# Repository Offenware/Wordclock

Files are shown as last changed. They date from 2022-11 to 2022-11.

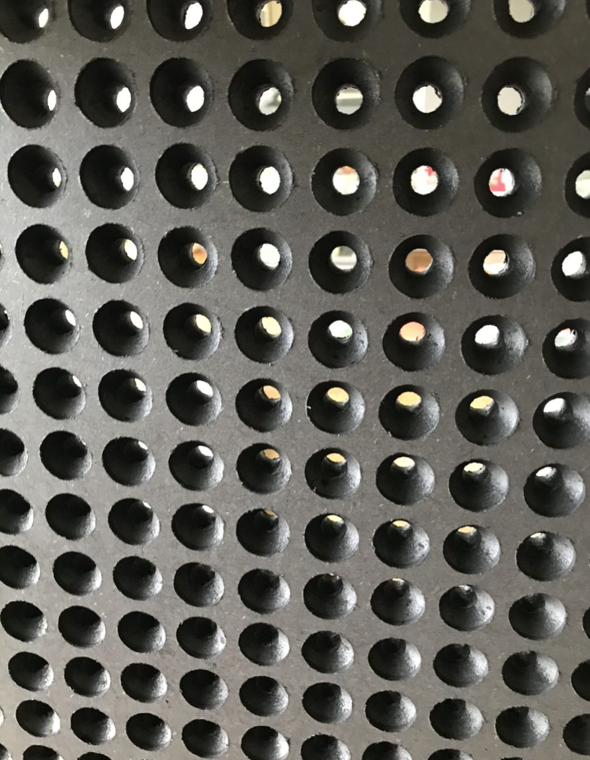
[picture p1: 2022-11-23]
Photos/Knipsel6.PNG

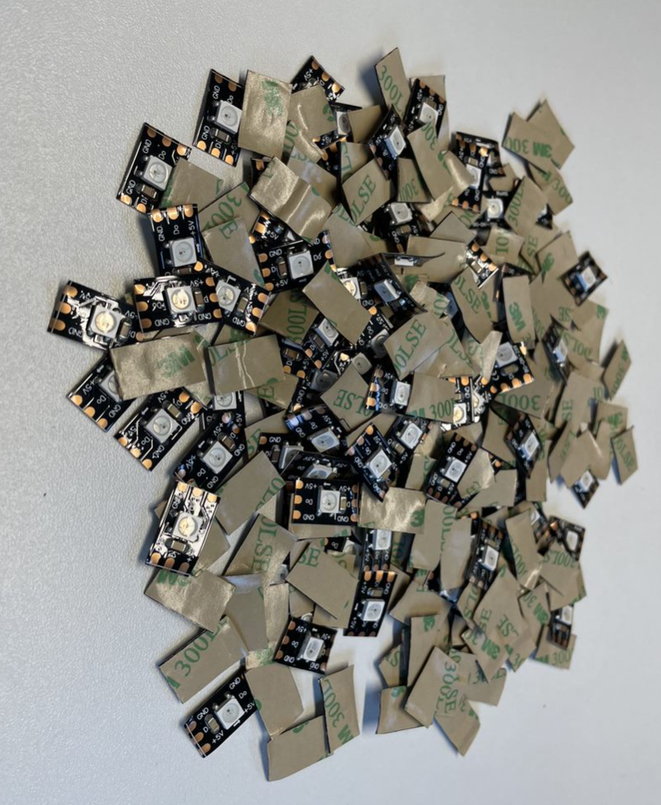
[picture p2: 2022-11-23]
Photos/Knipsel8.PNG

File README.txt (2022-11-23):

# Wordclock
THIS IS NOT A MANUAL, YOU HAVE TO FIGURE OUT HOW TO BUILD IT YOURSELF

Added pictures for some clarity

These are the sources for my Wordclock project. 
Lots of things are in Dutch since I never planned to go public with it, so you have to do some figuring out.
On the other hand, I figured out a lot that you now can use.
Also, be aware that still a lot of improvements can be made on both software and components.

I used a lot of stuff that's on the internet to start out with, so most of it is not originally mine.

The faceplate
I created the face plate in Inkscape and adjusted the DroidSansMono.ttf to meet my needs in FontForge
https://inkscape.org/release/inkscape-1.2.1/windows/64-bit/msi/?redirected=1
https://fontforge.org/en-U

For hardware I used:
5 meters WS2812b digital RGB ledstrip Premium Model: DS12BLS60-05M0520
40 Watt - 5V / 8A adapter for USB led strips Model: AD05-08PT
Between the Faceplate and the Backplate I used a sample of ORACAL® 8500 Translucent Color: 8500-010 White
The Backplate is MDF black 500x500 mm, 22 mm thick
Arduino Mega2560Pro
nodemcu esp32-s 38 pins (many types available)
DS3231 clock
BME260 sensor for fun
Diode and resisters where needed

Designed PCB's to hold the LEDs and the Arduino and Clock etc, designed them in Fritzing, ordered it at https://aisler.net/

Tip: Don't solder the Leds on the backstrips any hotter than 290 degrees Celcius or they'll get damaged and you'll spend a lot of time replacing bad ones.
Talking from experience here :-(

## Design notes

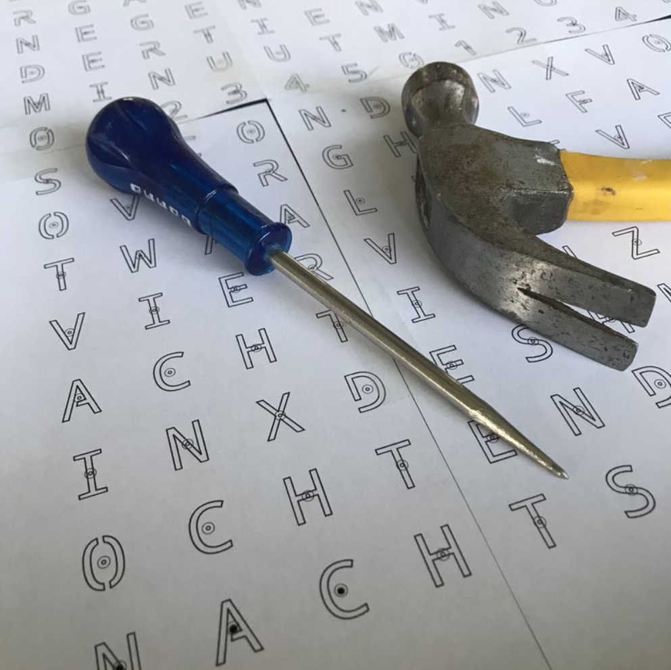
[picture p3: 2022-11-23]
Photos/Knipsel2.PNG

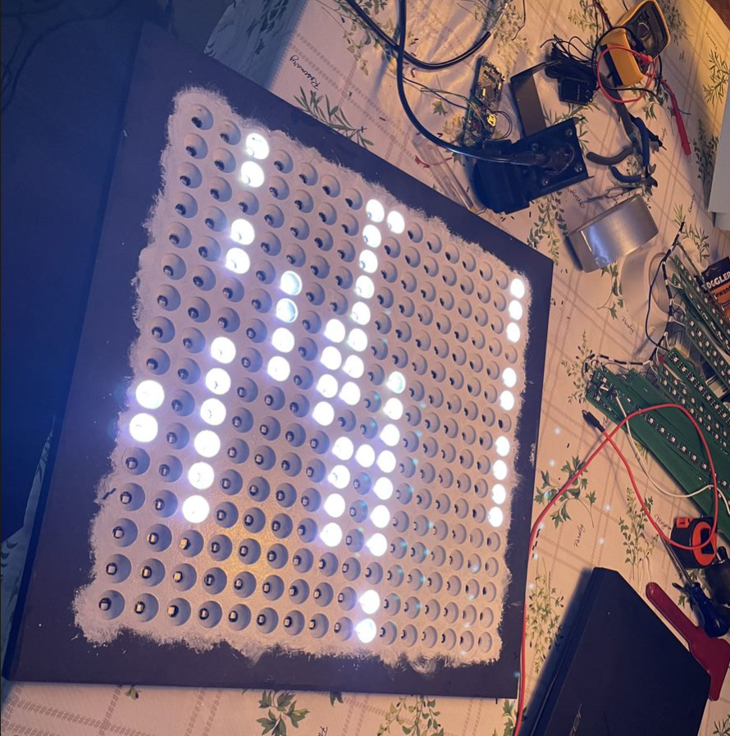
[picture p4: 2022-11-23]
Photos/Knipsel16.PNG

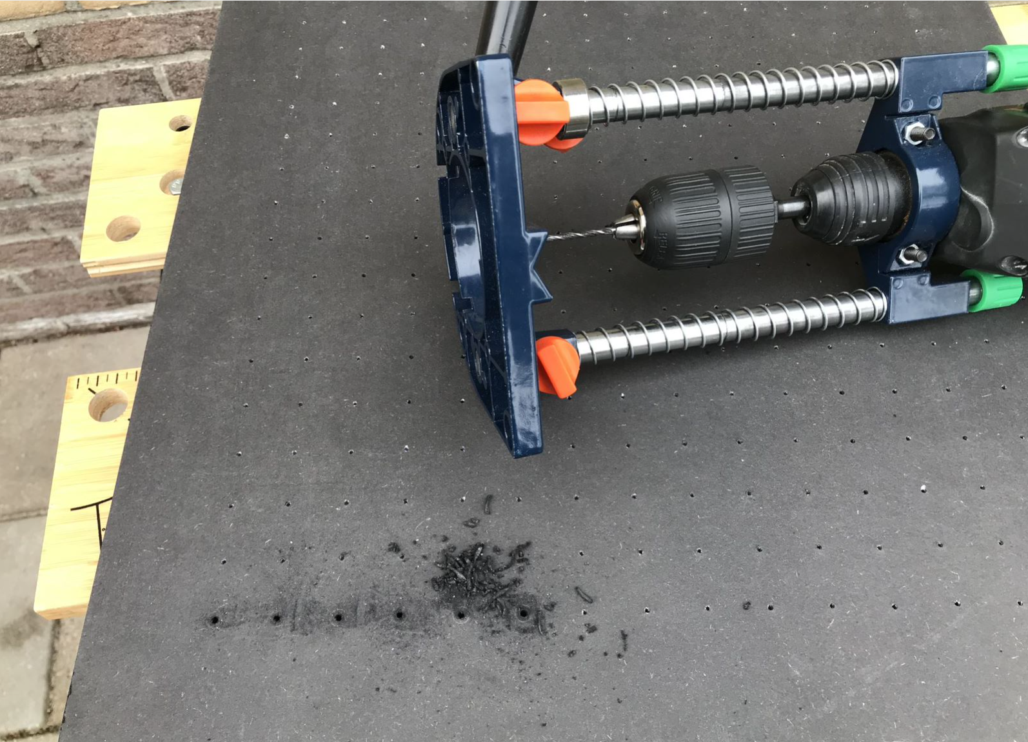
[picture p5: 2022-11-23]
Photos/Knipsel3.PNG

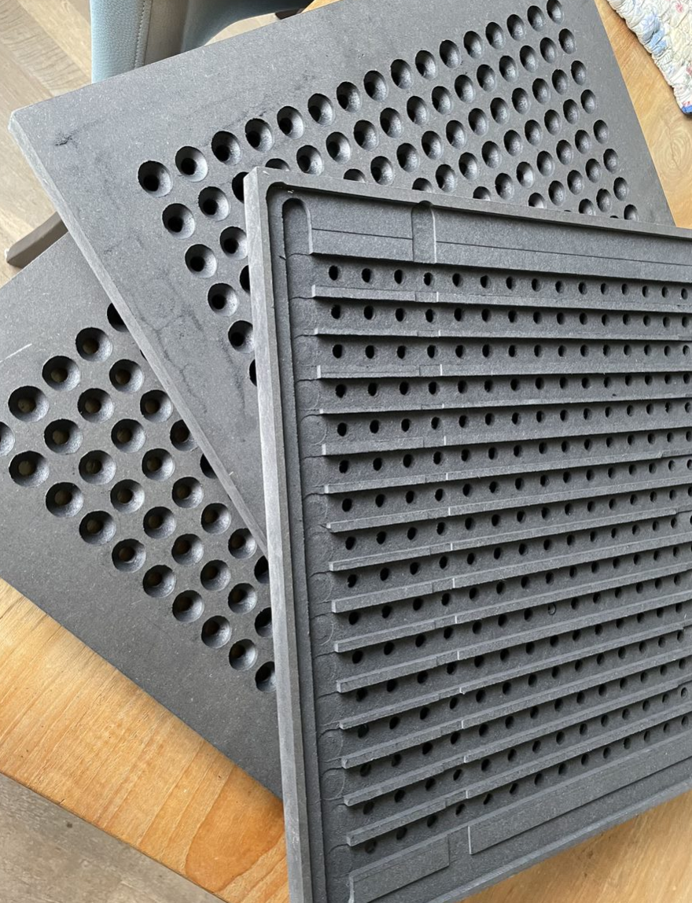
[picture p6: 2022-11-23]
Photos/Knipsel11.PNG

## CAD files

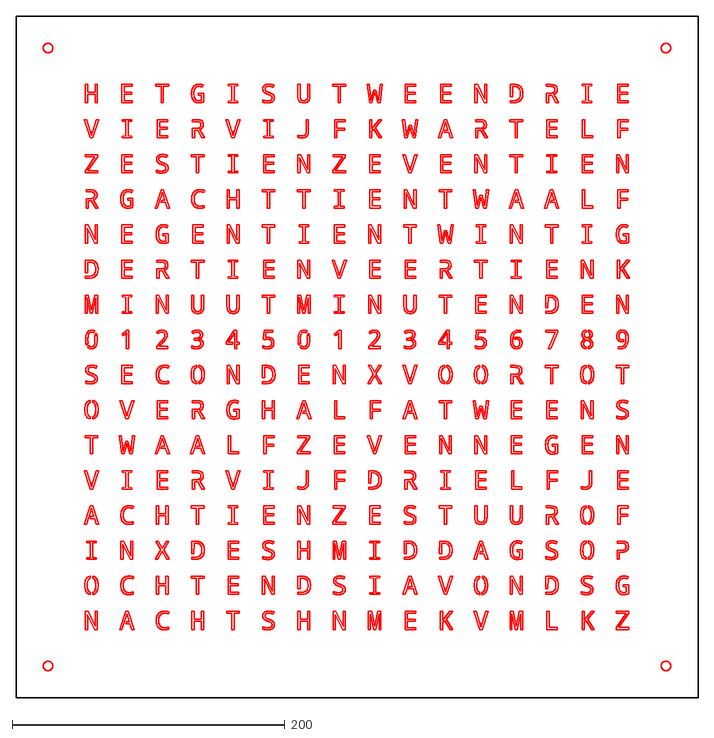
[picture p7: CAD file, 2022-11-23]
Faceplate/wettersnijer.dxf
500.0 x 500.0

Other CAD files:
Faceplate/Inkscape/voorkant.dxf

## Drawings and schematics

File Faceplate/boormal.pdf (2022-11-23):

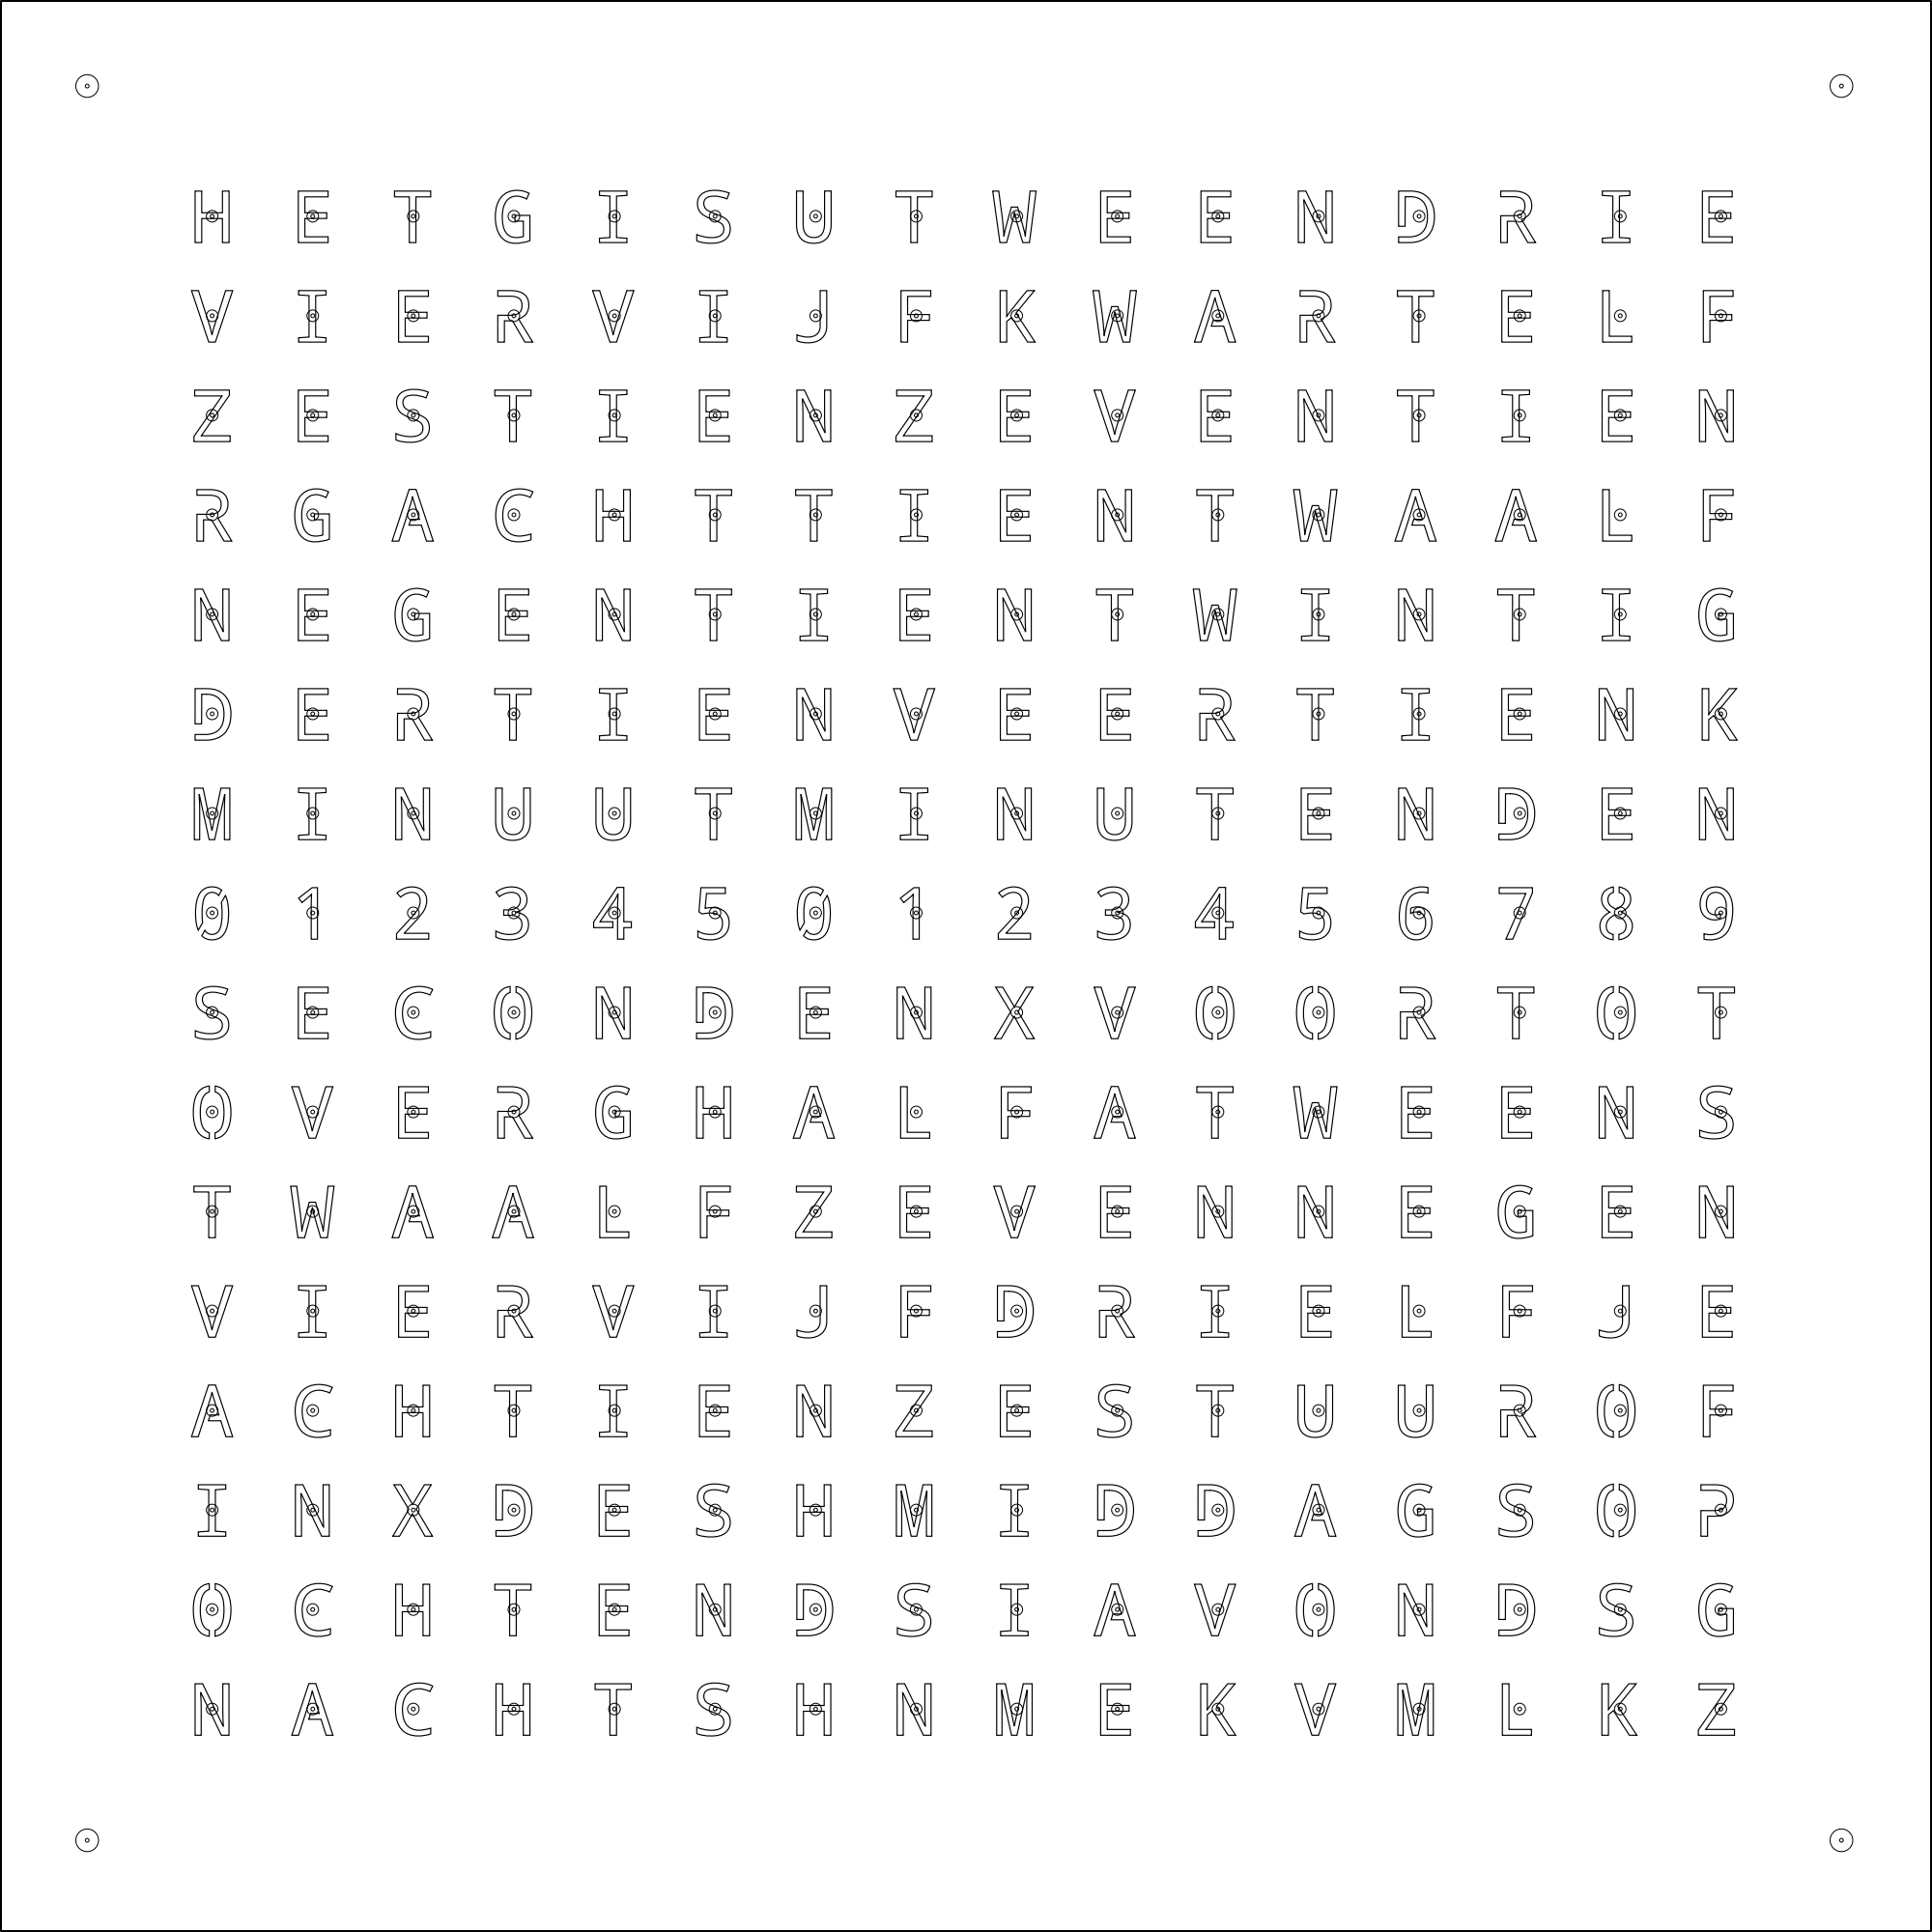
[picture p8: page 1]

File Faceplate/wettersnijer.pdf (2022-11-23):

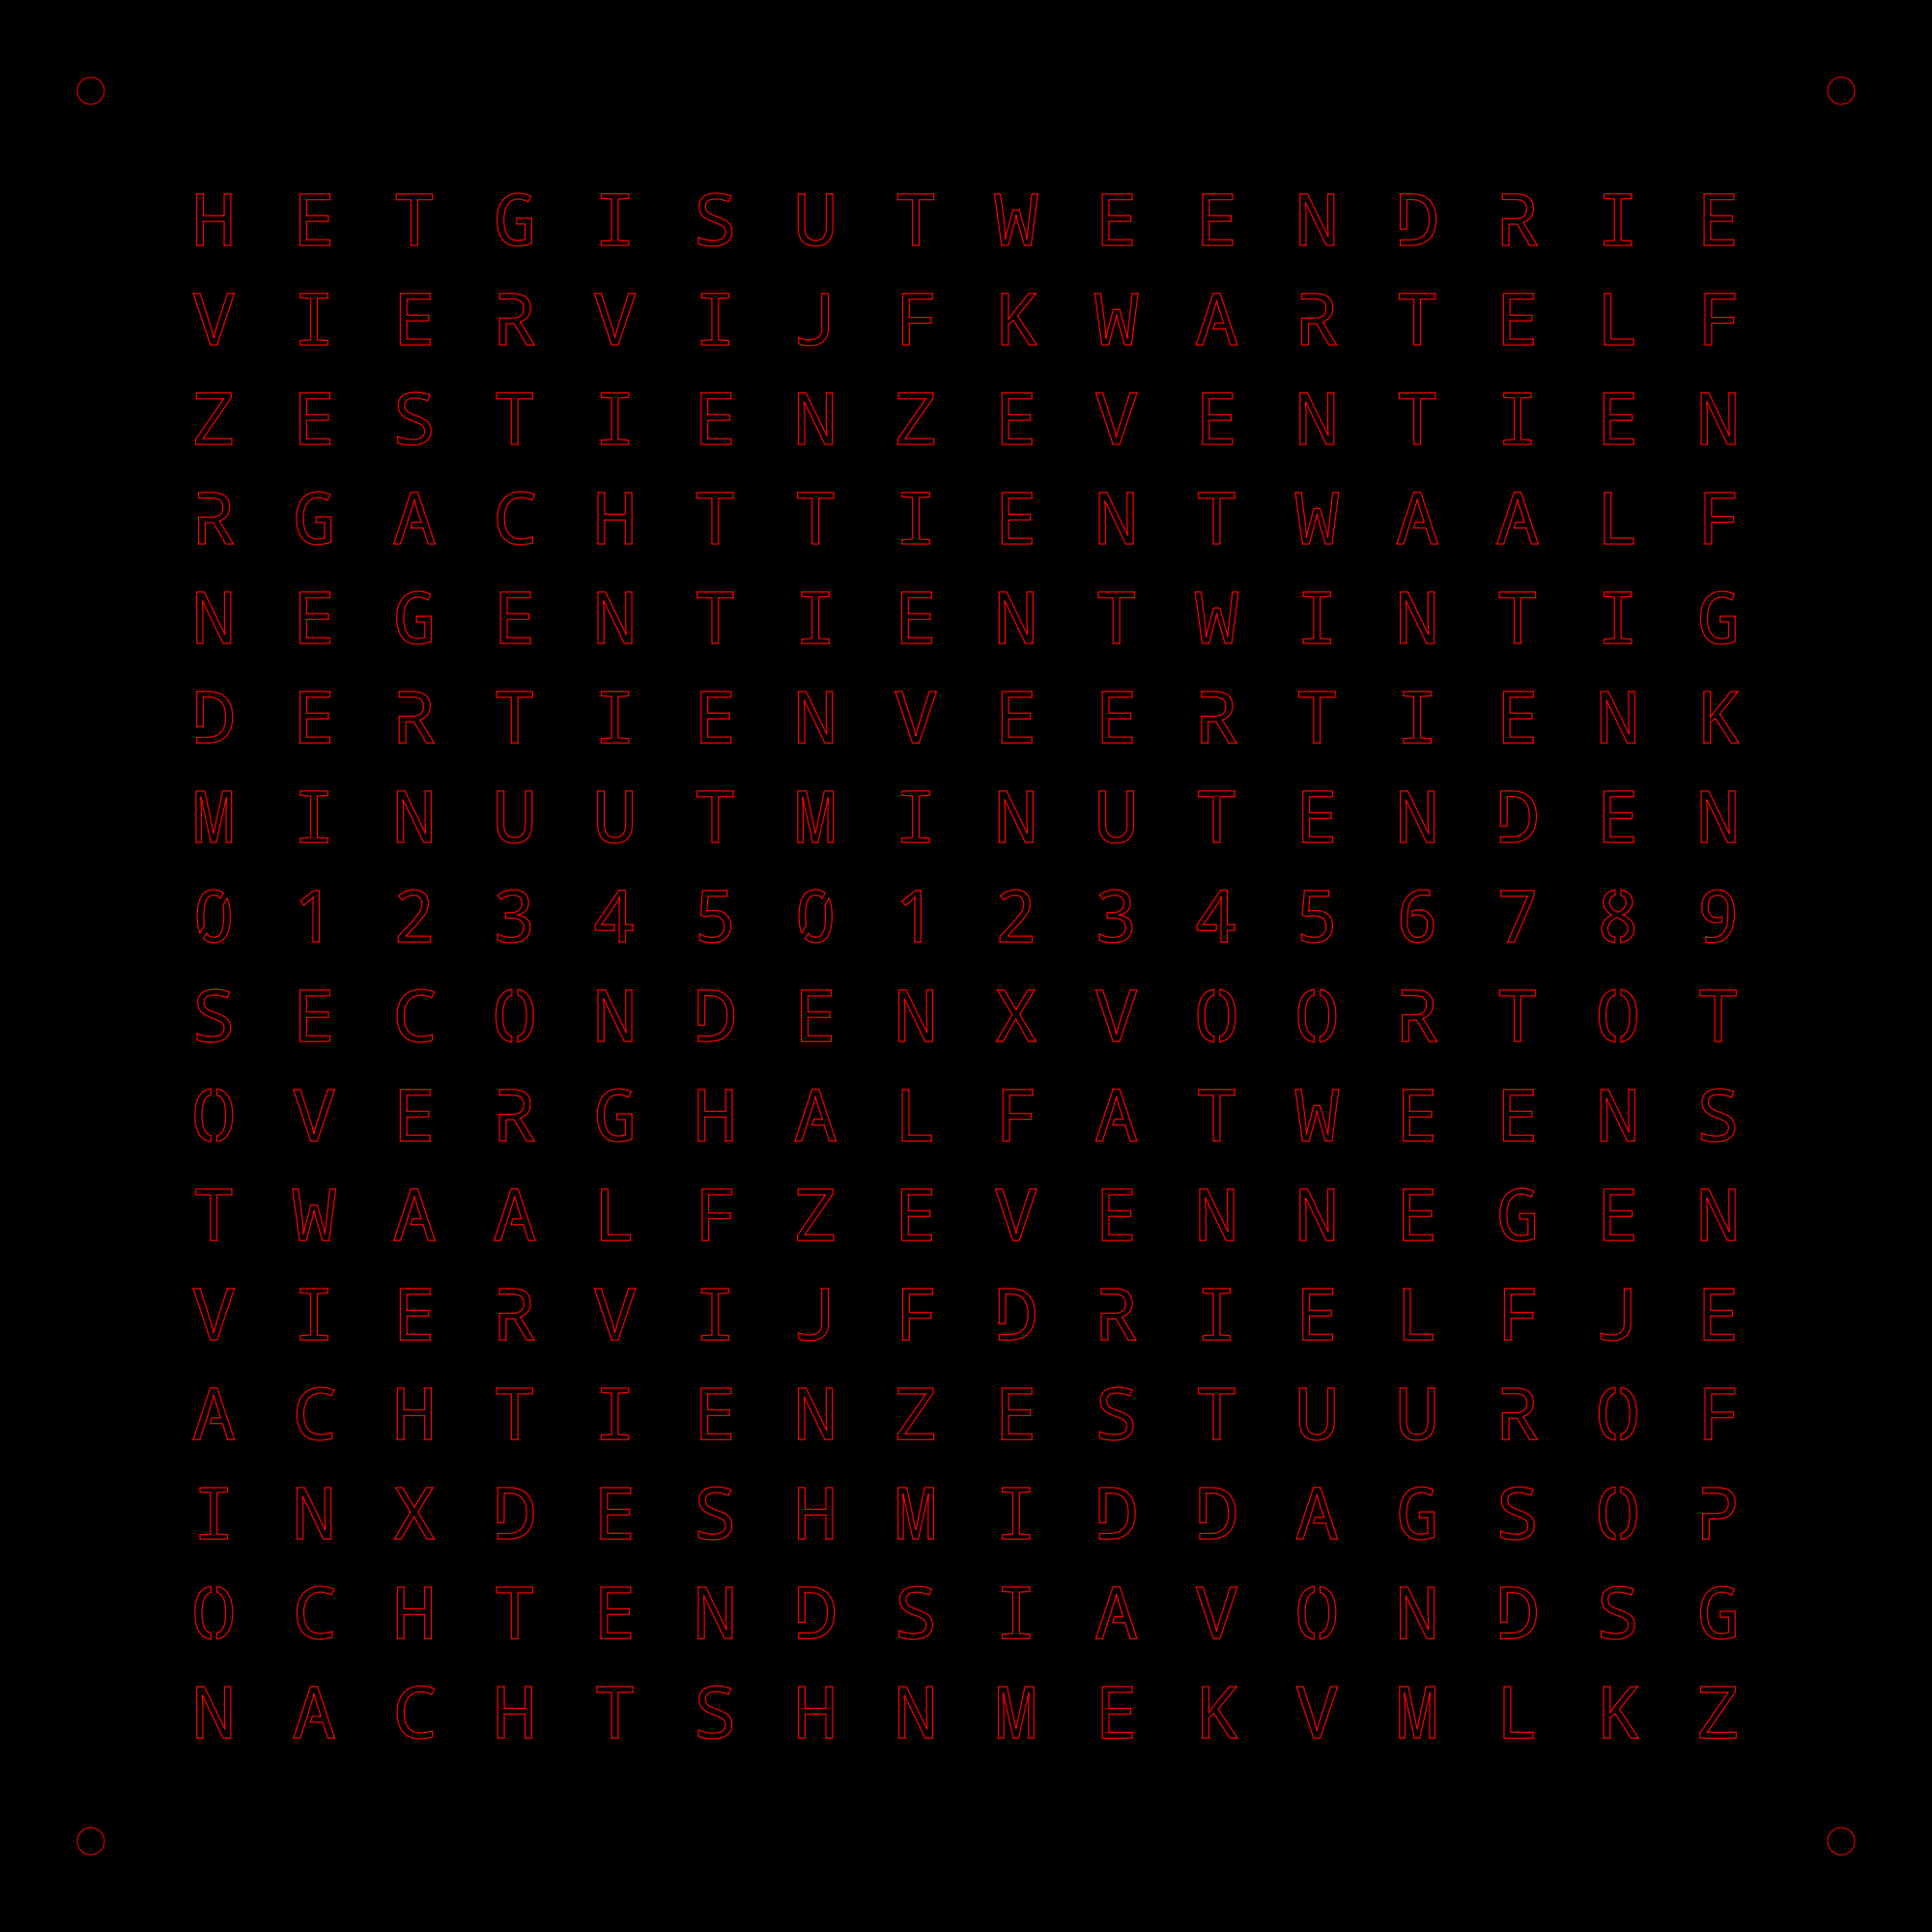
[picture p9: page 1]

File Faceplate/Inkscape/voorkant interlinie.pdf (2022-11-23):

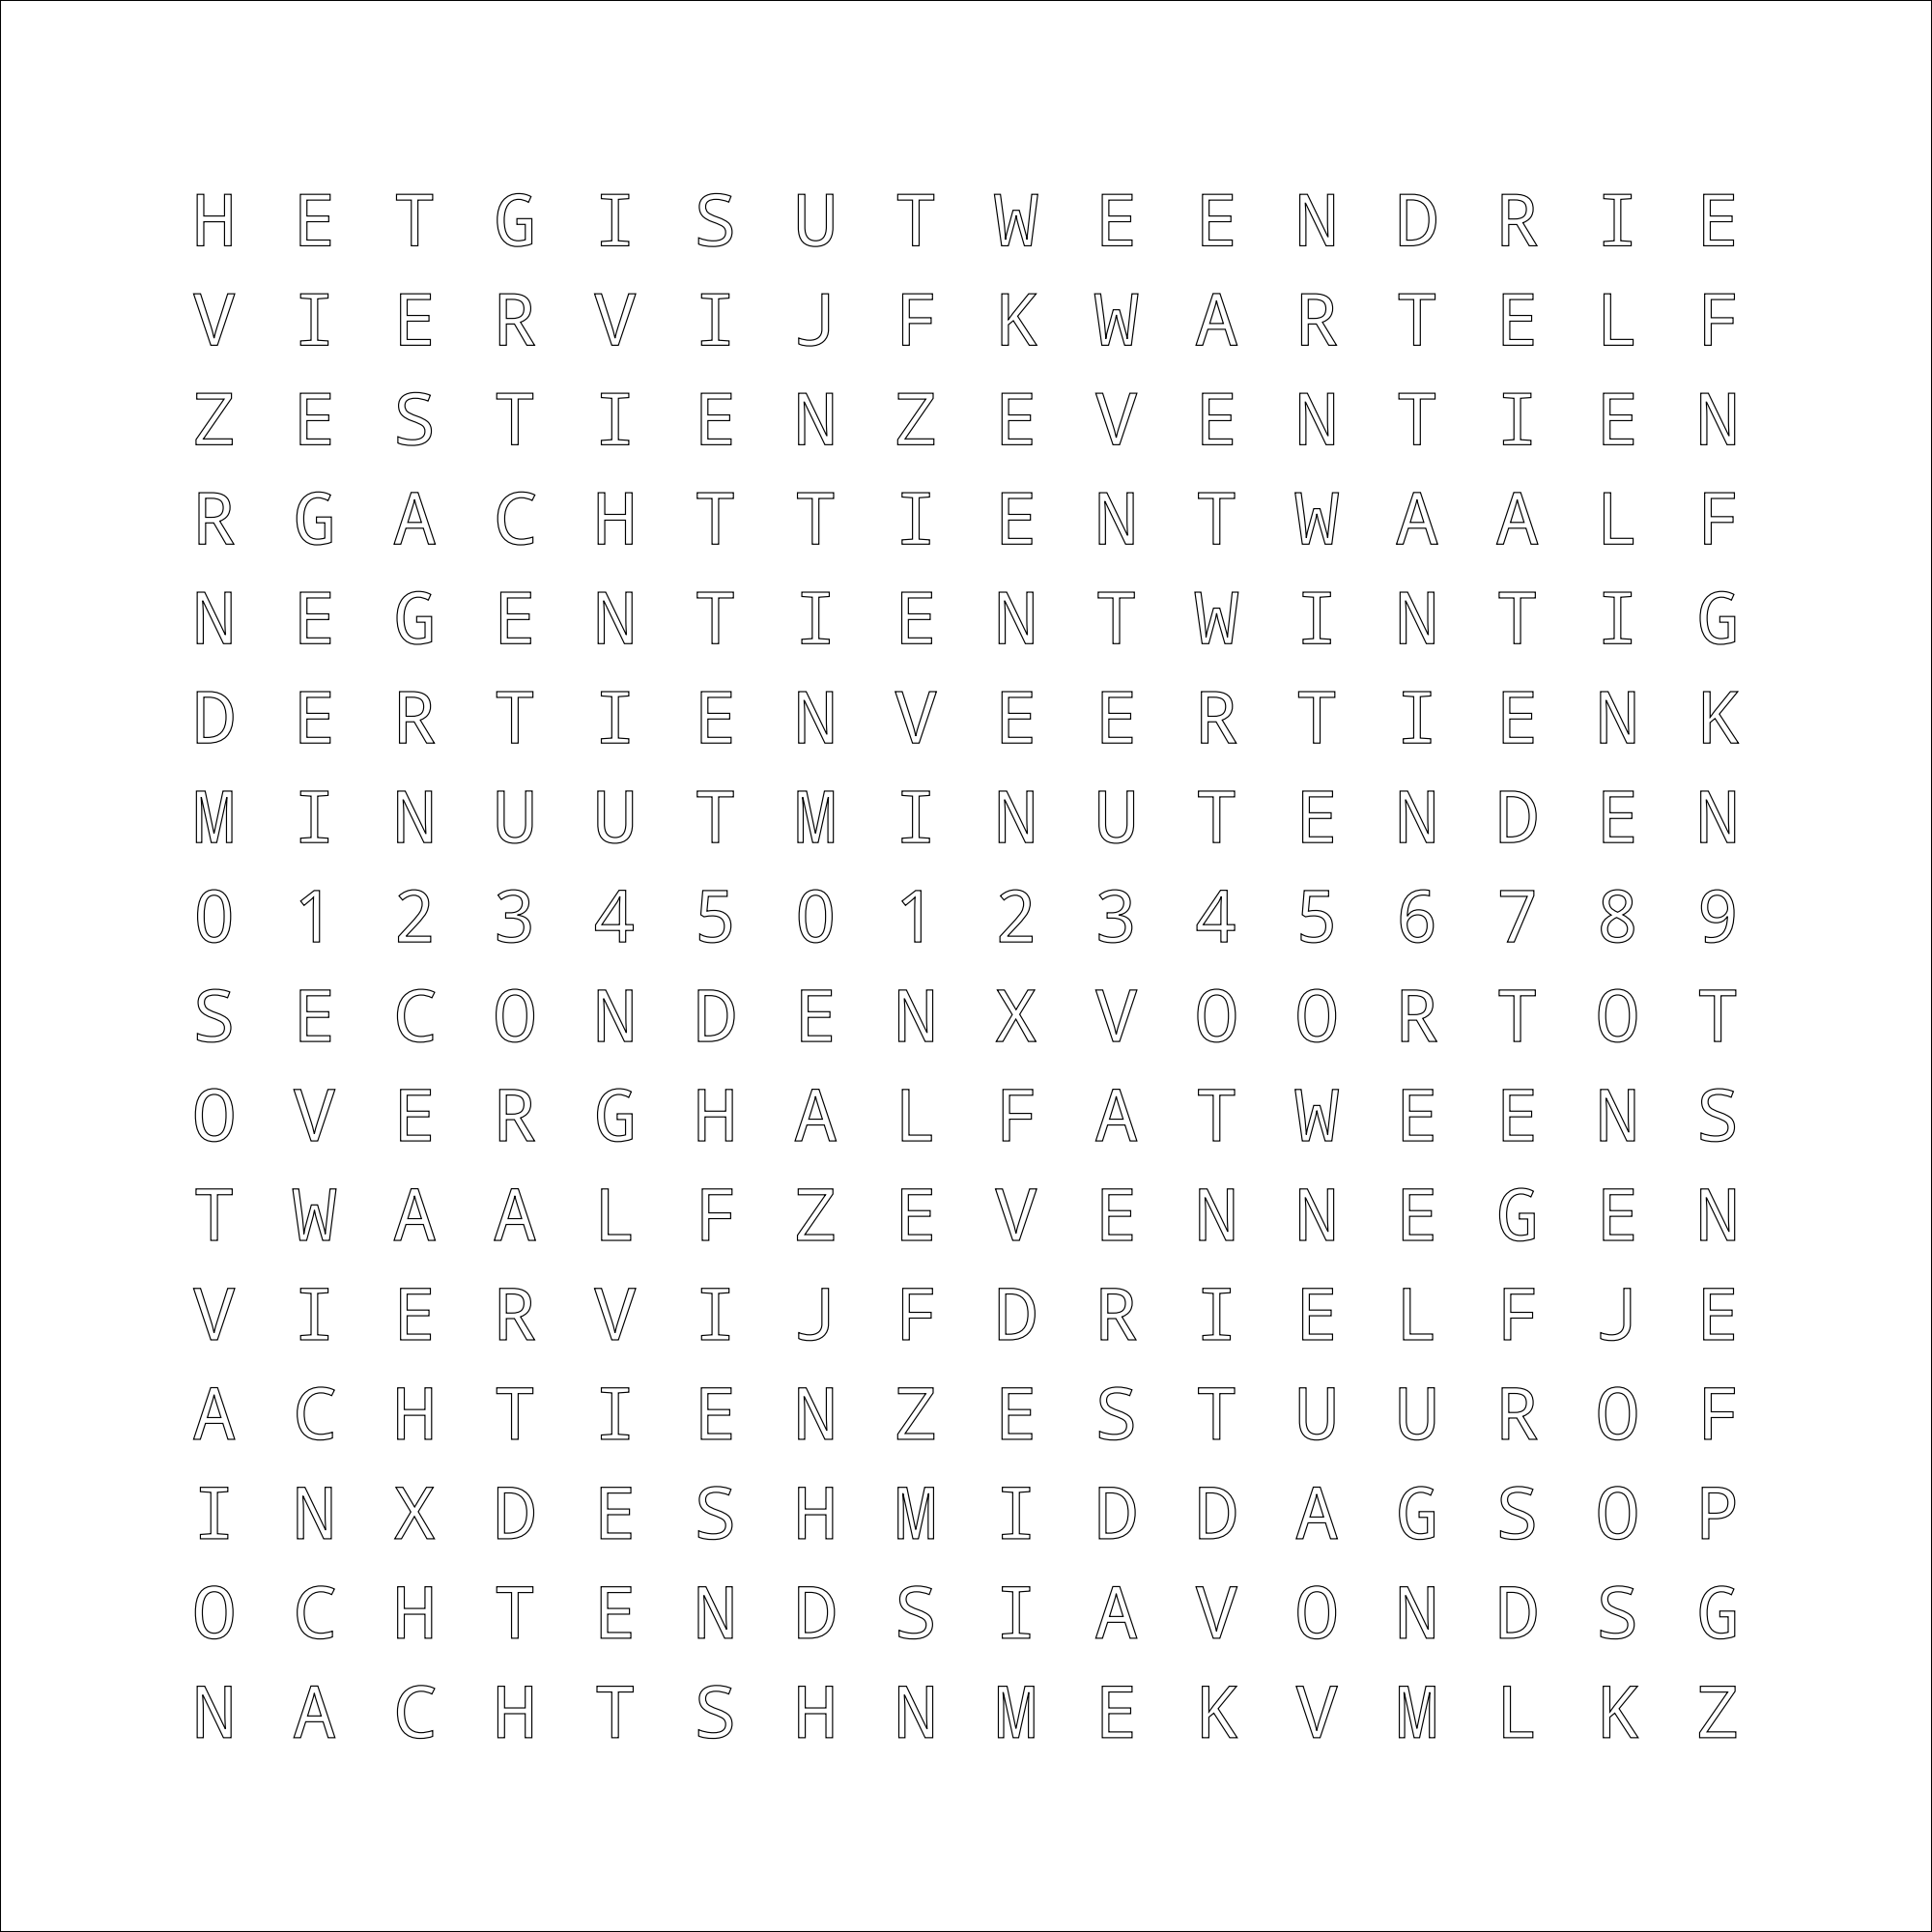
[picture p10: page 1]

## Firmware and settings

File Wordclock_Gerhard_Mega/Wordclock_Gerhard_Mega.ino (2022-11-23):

/*

Word Clock
Copyright (C) 2015 by Xose Pérez <xose dot perez at gmail dot com>
Copyright (C) 2021 Modified by Gerhard Bouma

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
*/


#include <Arduino.h>
#include <ArduinoJson.h>
#include <Wire.h>
#include <Adafruit_NeoPixel.h>
#include <Adafruit_Sensor.h>
#include <Adafruit_BME280.h>

#include <gbTime.h>         //http://www.arduino.cc/playground/Code/Time  
#include <gbTimeLib.h>
#include <RTClib.h> // 0x68

#include "wordclock.h"
#include "nederlands.h"
#include "TimeLord.h"

#include "MoonPhase.h"

// =============================================================================
// Globals
// =============================================================================
MoonPhase mp;
unsigned long _next_1000_ms;
unsigned long _millis;

int current_year;
int current_month;
int current_day;
int current_hour;
int current_minute;
int current_second;

int zon_op_uu;
int zon_op_mm;
int zon_onder_uu;
int zon_onder_mm;
int tellerop = 0;

uint32_t wit;
uint32_t rood;
uint32_t groen;
uint32_t blauw;
uint32_t geel;
uint32_t oranje;

unsigned long startDimmen;
unsigned long eindeDimmen;
unsigned long eindeOpdraaien;
unsigned long startOpdraaien;

color_struct kleurtje[6];
color_struct regenboog[16];

uint8_t mode;
uint8_t minBrightness;
uint8_t maxBrightness;
uint8_t stepBrightness; //in seconden
uint8_t startBrightness; //gerekend in minuten voor zonsondergang
uint8_t bRood; 
uint8_t bGroen; 
uint8_t bBlauw; 
uint8_t bSRood; 
uint8_t bSGroen; 
uint8_t bSBlauw; 
uint8_t uuruit; 
uint8_t uuraan; 
uint8_t nachtsterkte; 
uint8_t bWordclock; 
uint8_t bEffect; 
uint8_t maan; 
uint8_t desOchtends; 
uint8_t hetIs; 

uint32_t kleur;
uint32_t kleurSec;

// what is our longitude (west values negative) and latitude (south values negative)
float longitude;
float latitude;

String wordclock = "secaan";
String effect = "geeneffect";
String effectOud;
uint8_t modeOud;

// The matrix array holds the time pattern matrix values
// De time_pattern bevat MATRIX_HEIGHT regels met daarin MATRIX_WIDTH tekens
unsigned int time_pattern[MATRIX_HEIGHT] = {0};

uint8_t brightness = DEFAULT_BRIGHTNESS;
uint8_t tabBrightness;

int _druk; // doorgeefluikje, heb geen zin het anders te doen

boolean ledState = 0;
boolean toggle = false;
boolean isZomertijd = false;
boolean autoZomertijd = true;
boolean opstarten = true;
boolean gedimd = false;

boolean berichtOntvangenOK = false;
boolean berichtOntvangenNOK = false;

// Allocate the JSON document
// This one must be bigger than for the sender because it must store the strings
StaticJsonDocument<600> docIn;
StaticJsonDocument<600> docUit;
DeserializationError err;

// =============================================================================
// Pixel matrix
// =============================================================================
Adafruit_NeoPixel matrix = Adafruit_NeoPixel(TOTAL_PIXELS, PIN_LEDmatrix, NEO_GRB + NEO_KHZ800);

// =============================================================================
// RTC
// =============================================================================
RTC_DS3231 rtc;

// =============================================================================
// BME
// =============================================================================
#define SEALEVELPRESSURE_HPA (1013.76)
Adafruit_BME280 bme; // I2C

boolean vlagje = false;

// =============================================================================
// Methods
// =============================================================================

void eeprom_save() {

  // https://www.arduino.cc/en/Reference/EEPROMPut
  
  int eeAddress = 0;   //Location we want the data to be put.
  
  if (wordclock == "secaan") {
    bWordclock = 1;
  } else if (wordclock == "secuit") {
    bWordclock = 2;
  } else if (wordclock == "seckleur") {
    bWordclock = 3;
  }
  
  if (effect == "geeneffect") {
    bEffect = 1;
  } else if (effect == "vlag") {
    bEffect = 2;
  } else if (effect == "regenboog") {
    bEffect = 3;
  } else if (effect == "gradient") {
    bEffect = 4;
  }

  //Data to store.
  MyObject customVar = {
    mode,
    minBrightness,
    maxBrightness,
    stepBrightness,
    startBrightness,
    bRood,
    bGroen, 
    bBlauw, 
    bSRood, 
    bSGroen, 
    bSBlauw,
    uuruit, 
    uuraan, 
    nachtsterkte, 
    bWordclock, 
    bEffect, 
    maan, 
    desOchtends, 
    hetIs, 
    autoZomertijd 
  };

  EEPROM.put(eeAddress, customVar);

  eeAddress = 19;
  EEPROM.put(eeAddress, longitude);
  
  eeAddress += sizeof(float); //Move address to the next byte after float 'f'.
  EEPROM.put(eeAddress, latitude);

}

void eeprom_retrieve() {

  // https://www.arduino.cc/en/Reference/EEPROMGet
  
  int eeAddress = 0; //EEPROM address to start reading from
   
  MyObject customVar; //Variable to store custom object read from EEPROM.
  EEPROM.get(eeAddress, customVar);

  eeAddress = 19;
  EEPROM.get(eeAddress, longitude);
  
  eeAddress += sizeof(float); //Move address to the next byte after float 'f'.
  EEPROM.get(eeAddress, latitude);
 
  if (isnan(customVar.mode)) mode = MODE_CLOCK; mode = customVar.mode;
  if (isnan(customVar.startBrightness)) startBrightness = 60; startBrightness = customVar.startBrightness;
  if (isnan(customVar.stepBrightness)) stepBrightness = 30; stepBrightness = customVar.stepBrightness;
  if (isnan(customVar.minBrightness)) minBrightness = 11; minBrightness = customVar.minBrightness;
  if (isnan(customVar.maxBrightness)) maxBrightness = 255; maxBrightness = customVar.maxBrightness;
  if (isnan(customVar.bRood)) bRood = 255; bRood = customVar.bRood;
  if (isnan(customVar.bGroen)) bGroen = 255; bGroen = customVar.bGroen;
  if (isnan(customVar.bBlauw)) bBlauw = 255; bBlauw = customVar.bBlauw;
  if (isnan(customVar.bSRood)) bSRood = 255; bSRood = customVar.bSRood;
  if (isnan(customVar.bSGroen)) bSGroen = 255; bSGroen = customVar.bSGroen;
  if (isnan(customVar.bSBlauw)) bSBlauw = 255; bSBlauw = customVar.bSBlauw;
  if (isnan(customVar.uuruit)) uuruit = 23; uuruit = customVar.uuruit;
  if (isnan(customVar.uuraan)) uuraan = 7; uuraan = customVar.uuraan;
  if (isnan(customVar.nachtsterkte)) nachtsterkte = 12; nachtsterkte = customVar.nachtsterkte;
  if (isnan(customVar.bWordclock)) bWordclock = 1; bWordclock = customVar.bWordclock;
  if (isnan(customVar.bEffect)) bEffect = 1; bEffect = customVar.bEffect;
  if (isnan(customVar.maan)) maan = true; maan = customVar.maan;
  if (isnan(customVar.desOchtends)) desOchtends = false; desOchtends = customVar.desOchtends;
  if (isnan(customVar.hetIs)) hetIs = true; hetIs = customVar.hetIs;
  if (isnan(customVar.autoZomertijd)) autoZomertijd = true; autoZomertijd = customVar.autoZomertijd;

  if (bWordclock == 1) {
    wordclock = "secaan";
  } else if (bWordclock == 2) {
    wordclock = "secuit";
  } else if (bWordclock == 3) {
    wordclock = "seckleur";
  }
  
  if (bEffect == 1) {
    effect = "geeneffect";
  } else if (bEffect == 2) {
    effect = "vlag";
  } else if (bEffect == 3) {
    effect = "regenboog";
  } else if (bEffect == 4) {
    effect = "gradient";
  }
  
}

// Get pixel indexje in matrix from X,Y coords
unsigned int pixelindex(int karakter, int regel) {
  
  int ledpositie = regel * MATRIX_WIDTH;
  ledpositie += karakter;

  // de ledpositie is nu van 0-255, we willen 255-0
  ledpositie = 255 - ledpositie;
  return ledpositie;
  
}

/**
 * Prints current time part throu serial
 * @param  int  digits        Number to print
 * @param  bool semicolon     Whether to prepend a semicolon or not, defaults to false
 */
void printDigits(int digits, bool semicolon = false){
  
  if (semicolon) Serial.print(F(":"));
  if(digits < 10) Serial.print(F("0"));
  Serial.print(digits);
  
}

void drawScreen(const byte* buffertje, int offsetX, int offsetY, int breedte, int hoogte) { 
   
  for (int regel = 0; regel < hoogte; ++regel){
    for (int karakter = 0; karakter < breedte; ++karakter){
      const unsigned char mask = 1 << karakter; // shift 1 karakters naar links
      int pix = pixelindex(breedte - karakter - 1 + offsetX, regel + offsetY);
      if (buffertje[regel] & mask) { // Dit bit is geset
        Matrix_setPixelColor(pix, getColorSchema(pix));
      }
    }
  }
}

unsigned long getColorSchema(int pix) {
  
  if (mode == MODE_BAROMETER) {
    if (_druk <= LUCHTDRUK_LAAG) {
      return rood; 
    }
    if (_druk > LUCHTDRUK_LAAG and _druk <= LUCHTDRUK_HOOG) {
      return oranje;
    }
    if (_druk > LUCHTDRUK_HOOG) {
      return groen;
    }
  }
  
// =============================================================================
// Dutch flag colors
// =============================================================================
  if (effect == "vlag") {
    if (pix >= 0 and pix < (5 * 16)) {
      return blauw; 
    } else if (pix >= (5 * 16) and pix < (10 * 16)) {
      return wit; 
    } else if (pix >= (10 * 16)) {
      if ((current_month == 4 and current_day == 27)) {
        if (pix >= (15 * 16)) {
          return oranje;
        }
      }
      return rood;
    }
  }

  static int kleurstap = 0;
  static int hoofdkleur = 0;
  
// =============================================================================
// Rainbow colors
// =============================================================================
  if ((mode == MODE_CLOCK or mode == MODE_DIGICLOCK or mode == MODE_TEMPERATUUR) and effect == "regenboog") {
    int kolomNw = ((pix * 16) % 256 / 16);
    return Matrix_Color(ledLookupTable[regenboog[kolomNw].r], ledLookupTable[regenboog[kolomNw].g], ledLookupTable[regenboog[kolomNw].b]);
  }

// =============================================================================
// Gradient colors (shifting slowly over the spectrum)
// =============================================================================
  if ((mode == MODE_CLOCK or mode == MODE_DIGICLOCK or mode == MODE_TEMPERATUUR) and effect == "gradient") {
    int volgende = hoofdkleur + 1;
    if (volgende == 6) {
      volgende = 0;
    }
    
    if (pix == 255) {
      if (kleurstap++ >= 64) {
        kleurstap = 0;
        hoofdkleur++;
      }
    }
   
    if (hoofdkleur == 6) {
        hoofdkleur = 0;
        volgende = 1;
    }
    
    int red = map(kleurstap, 0, 64, kleurtje[hoofdkleur].r, kleurtje[volgende].r);  
    int green = map(kleurstap, 0, 64, kleurtje[hoofdkleur].g, kleurtje[volgende].g);    
    int blue = map(kleurstap, 0, 64, kleurtje[hoofdkleur].b, kleurtje[volgende].b);  

    return Matrix_Color(ledLookupTable[red], ledLookupTable[green], ledLookupTable[blue]);
  }
  
// =============================================================================
// Seconds different color
// =============================================================================
  if (mode == MODE_CLOCK) {
    if (wordclock == "seckleur" and ((pix >= ((8 * 16) - 8)) and (pix < ((10 * 16)- 14)))) {
      return kleurSec;
    } else {
      return kleur;  
    }
  }
  
  if (mode == MODE_DIGICLOCK) {
    if (wordclock == "seckleur" and ((pix >= 0 and pix < (9 * 16)))) {
      return kleurSec;
    } else {
      return kleur;  
    }
  }

  return kleur;  
}

void vulGRDigit(int digit, int pos, int nulpuntX, int nulpuntY) {

// =============================================================================
// Big digits
// =============================================================================
  byte dest[8] = {};
  int offsetX;
  int offsetY;
  
  switch (digit) {
    case 0:
      memcpy(dest, NR_NUL, GR_DIGIT_HOOGTE);
      break;
    case 1:
      memcpy(dest, NR_EEN, GR_DIGIT_HOOGTE);
      break;
    case 2:
      memcpy(dest, NR_TWEE, GR_DIGIT_HOOGTE);
      break;
    case 3:
      memcpy(dest, NR_DRIE, GR_DIGIT_HOOGTE);
      break;
    case 4:
      memcpy(dest, NR_VIER, GR_DIGIT_HOOGTE);
      break;
    case 5:
      memcpy(dest, NR_VIJF, GR_DIGIT_HOOGTE);
      break;
    case 6:
      memcpy(dest, NR_ZES, GR_DIGIT_HOOGTE);
      break;
    case 7:
      memcpy(dest, NR_ZEVEN, GR_DIGIT_HOOGTE);
      break;
    case 8:
      memcpy(dest, NR_ACHT, GR_DIGIT_HOOGTE);
      break;
    case 9:
      memcpy(dest, NR_NEGEN, GR_DIGIT_HOOGTE);
      break;
  }

  if (pos < 4) {
    offsetY = nulpuntY;
  } else {
    offsetY = nulpuntY + GR_DIGIT_HOOGTE + 1;
    pos = pos - 4;
  }

  offsetX = pos * (GR_DIGIT_BREEDTE + 1) + nulpuntX;
  
  drawScreen(dest, offsetX, offsetY, GR_DIGIT_BREEDTE, GR_DIGIT_HOOGTE);
}

void vulKLDigit(int digit, int pos, int nulpuntX, int nulpuntY) {

// =============================================================================
// Small digits
// =============================================================================
  byte dest[8] = {};
  int offsetX;
  int offsetY;
  
  switch (digit) {
    case 0:
      memcpy(dest, NR_NUL_KL, KL_DIGIT_HOOGTE);
      break;
    case 1:
      memcpy(dest, NR_EEN_KL, KL_DIGIT_HOOGTE);
      break;
    case 2:
      memcpy(dest, NR_TWEE_KL, KL_DIGIT_HOOGTE);
      break;
    case 3:
      memcpy(dest, NR_DRIE_KL, KL_DIGIT_HOOGTE);
      break;
    case 4:
      memcpy(dest, NR_VIER_KL, KL_DIGIT_HOOGTE);
      break;
    case 5:
      memcpy(dest, NR_VIJF_KL, KL_DIGIT_HOOGTE);
      break;
    case 6:
      memcpy(dest, NR_ZES_KL, KL_DIGIT_HOOGTE);
      break;
    case 7:
      memcpy(dest, NR_ZEVEN_KL, KL_DIGIT_HOOGTE);
      break;
    case 8:
      memcpy(dest, NR_ACHT_KL, KL_DIGIT_HOOGTE);
      break;
    case 9:
      memcpy(dest, NR_NEGEN_KL, KL_DIGIT_HOOGTE);
      break;
  }

  if (pos < 4) {
    offsetY = nulpuntY;
  } else {
    offsetY = nulpuntY + KL_DIGIT_HOOGTE + 1;
    pos = pos - 4;
  }

  offsetX = pos * (KL_DIGIT_BREEDTE + 1) + nulpuntX;
  
  drawScreen(dest, offsetX, offsetY, KL_DIGIT_BREEDTE, KL_DIGIT_HOOGTE);
  
}

// =============================================================================
// === CLOCK ===================================================================
// =============================================================================
/**
 * Displays time through serial
 * @param  DateTime now           DateTime object
 */
void digitalClockDisplay(){
  
  Serial.print(F("Time: "));
  printDigits(current_year, false);
  Serial.print("-");
  printDigits(current_month, false);
  Serial.print("-");
  printDigits(current_day, false);
  Serial.print(" ");

  printDigits(current_hour, false);
  printDigits(current_minute, true);
  printDigits(current_second, true);

  Serial.println();
  
}

/**
 * Loads current time pattern in time_pattern matrix
 */
void prepareTimePattern() {

  DateTime now = rtc.now();
  current_year = now.year();
  current_month = now.month();
  current_day = now.day();
  current_hour = now.hour();
  current_minute = now.minute();
  current_second = now.second();

// =============================================================================
// This is a bit complicated. In effect it calculates based on sunup or sundown how fast to lower/increase light intensity en when it should be done
// All configurable through the web interface on the ESP32
// =============================================================================

  //=============================================================
  // Bepalen lichtsterkte
  //=============================================================
  if (isZomertijd) {
    current_hour++;
    if (current_hour > 23) {
      current_hour -= 24;
    }
  }

  if (current_hour == 2 and current_minute == 0 and current_second == 00 or zon_op_uu == 0){
    bepaalZonOpOnder();
  }

  //                      opdraaien                  zonop                                            zononder   dimmen
  //---------------------*------------------------&--|------------------------------------------------------|--*-------------------------&-------------------
  //                              periode                                                                             periode   
  
  unsigned long nu = (current_hour * 3600L) + (current_minute * 60L) + current_second; 
 
  //Het verschil tussen min en max maal het aantal stappen 
  //maxBrightness: de hoogste stap
  //minBrightness: de laagste stap
  //stepBrightness: per dit aantal seconden een stap op of neer in lichtsterkte 
  
  unsigned long periode = (maxBrightness - minBrightness) * stepBrightness; // dit aantal seconden wordt er gedimd of opgedraaid
 
  //startBrightness: gerekend in minuten voor zonsondergang of na zonsopkomst
  startDimmen = (zon_onder_uu * 3600L) + (zon_onder_mm * 60L) - (startBrightness * 60L);
  eindeDimmen = startDimmen + periode;

  eindeOpdraaien = (zon_op_uu * 3600L) + (zon_op_mm * 60L) + (startBrightness * 60L);
  startOpdraaien = eindeOpdraaien - periode;

  boolean dimmen = false;
  boolean opdraaien = false;
  unsigned long periodeVerstreken = 0; // Hoe lang het dimmen of opdraaien al bezig is
  
  if (nu >= startDimmen and nu <= eindeDimmen) {
    dimmen = true;
  } else if (nu >= startOpdraaien and nu <= eindeOpdraaien) {
    opdraaien = true;
  } else if (nu < startOpdraaien or nu > eindeDimmen) {
    tabBrightness = minBrightness;
  } else if (nu < startDimmen and nu > eindeOpdraaien) {
    tabBrightness = maxBrightness;
  }

  if (dimmen) {
    periodeVerstreken = nu - startDimmen;
    tabBrightness = maxBrightness - (periodeVerstreken / stepBrightness);
  }

  if (opdraaien) {
    periodeVerstreken = nu - startOpdraaien;
    tabBrightness = minBrightness + (periodeVerstreken / stepBrightness);
  }

  if (tabBrightness > maxBrightness) tabBrightness = maxBrightness;
  if (tabBrightness < minBrightness) tabBrightness = minBrightness;
  
  if (uuraan != uuruit) {
    if (current_hour >= uuruit ) {
      tabBrightness = nachtsterkte;
    }
    if (current_hour < uuraan) {
      tabBrightness = nachtsterkte;
    }
  }

// =============================================================================
// Don't turn on leds full blast right away
// =============================================================================
  // Langzaam opstarten, beter voor de leds etc
  if (ledLookupTable[tabBrightness] > brightness + 20) {
    opstarten = true;
  }
  
  if (brightness >= 245) {
    opstarten = false;
  }
  
  if (opstarten) {
    if (brightness < ledLookupTable[tabBrightness]) {
      brightness = brightness + 10;
    } else {
      brightness = ledLookupTable[tabBrightness];
      opstarten = false;
    }
  } else {
    brightness = ledLookupTable[tabBrightness];
  }

}
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
void loop() {

  // Check if the ESP32 is transmitting
  if (Serial1.available() >= 1) {
    // Read the JSON document from the "link" serial port
    err = deserializeJson(docIn, Serial1);

    if (err == DeserializationError::Ok) {
      
      berichtOntvangenOK = true;
      // (we must use as<T>() to resolve the ambiguity)
      mode = docIn["mode"].as<byte>();

      if (docIn["uur"].as<byte>() > 0) {
        struct tm timeinfo;
        timeinfo.tm_year = docIn["jaar"].as<byte>() + 1900;
        timeinfo.tm_mon = docIn["maand"].as<byte>();
        timeinfo.tm_mday = docIn["dag"].as<byte>();
        timeinfo.tm_hour = docIn["uur"].as<byte>();
        timeinfo.tm_min = docIn["minuut"].as<byte>();
        timeinfo.tm_sec = docIn["seconde"].as<byte>();
        rtc.adjust(DateTime(timeinfo.tm_year, timeinfo.tm_mon, timeinfo.tm_mday, timeinfo.tm_hour, timeinfo.tm_min, timeinfo.tm_sec));
        bepaalZonOpOnder();
      } 
             
      bRood = docIn["rood"].as<byte>();
      bGroen = docIn["groen"].as<byte>();
      bBlauw = docIn["blauw"].as<byte>();
      kleur = Matrix_Color(bRood, bGroen, bBlauw);
      
      bSRood = docIn["srood"].as<byte>();
      bSGroen = docIn["sgroen"].as<byte>();
      bSBlauw = docIn["sblauw"].as<byte>();
      kleurSec = Matrix_Color(bSRood, bSGroen, bSBlauw);

      minBrightness = docIn["minBrightness"].as<byte>();
      maxBrightness = docIn["maxBrightness"].as<byte>();
      stepBrightness = docIn["stepBrightness"].as<byte>();
      startBrightness = docIn["startBrightness"].as<byte>();

      float _longitude = docIn["lengtegraad"].as<float>();
      float _latitude = docIn["breedtegraad"].as<float>();

      if (_longitude == 0) {
        longitude = 5.69;
        bepaalZonOpOnder();
      } else {
        if (longitude != _longitude) {
          longitude = _longitude;
          bepaalZonOpOnder();
        }
      }

      if (_latitude == 0) {
        latitude = 53.03;
        bepaalZonOpOnder();
      } else {
        if (latitude != _latitude) {
          latitude = _latitude;
          bepaalZonOpOnder();
        }
      }

      uuraan = docIn["uuraan"].as<byte>();
      uuruit = docIn["uuruit"].as<byte>();
      nachtsterkte = docIn["nachtsterkte"].as<byte>();

      wordclock = docIn["wordclock"].as<String>();
      effect = docIn["effect"].as<String>();
      
      if (gedimd) {
        effectOud = effect;
        effect = "geeneffect";
        modeOud = mode;
        mode = MODE_CLOCK;
      }

      maan = docIn["maan"].as<byte>(); 
      desOchtends = docIn["desOchtends"].as<byte>(); 
      hetIs = docIn["hetIs"].as<byte>(); 

      autoZomertijd = docIn["zomer"].as<byte>(); 

      eeprom_save();
   
    } else {
      // Print error to the "debug" serial port
      berichtOntvangenNOK = true;
      Serial.print("deserializeJson() returned ");
      Serial.println(err.c_str());

      // Flush all bytes in the "link" serial port buffer
      while (Serial1.available() >= 1) {
        Serial1.read();
      }
    }
  }

   
  if (millis() < _millis) {
    _next_1000_ms = millis();
  }

  _millis = millis();
  
  if (millis() >= _next_1000_ms) {
    _next_1000_ms = millis() + 1000L;
    vlagje = true;
  }

  // Update display
  update();
  
  if (vlagje) {
    // De update moet eerst
    sendStatus();
    digitalWrite(LED_BUILTIN, !digitalRead(LED_BUILTIN));
  }

  vlagje = false;

}

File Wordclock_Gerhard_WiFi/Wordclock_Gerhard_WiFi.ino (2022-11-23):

// Board: NodeMCU-32S
//.https://randomnerdtutorials.com/installing-the-esp32-board-in-arduino-ide-windows-instructions/
// https://randomnerdtutorials.com/esp32-mqtt-publish-subscribe-arduino-ide/
/*
  Rui Santos
  Complete project details
   - Arduino IDE: https://RandomNerdTutorials.com/esp32-ota-over-the-air-arduino/
   - VS Code: https://RandomNerdTutorials.com/esp32-ota-over-the-air-vs-code/
  
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
  The above copyright notice and this permission notice shall be included in all
  copies or substantial portions of the Software.
*/
// https://m1cr0lab-esp32.github.io/remote-control-with-websocket/websocket-data-exchange/
// https://techtutorialsx.com/2019/03/04/esp32-arduino-serving-bootstrap/

// Import required libraries
#include <Arduino.h>
#include <ESPAsyncWebServer.h>
#include "SPIFFS.h"
#include <ArduinoJson.h>
#include <Arduino_JSON.h>
#include <AsyncElegantOTA.h>

#include <WiFi.h>
#include "time.h"

// include library to read and write from flash memory
#include <Preferences.h>
//#include <nvs_flash.h>

#define RXD2 16
#define TXD2 17
#define SERIAL_BAUD 115200

// Overige modes gaan hier dwars doorheen naar de klok, alleen opnemen indien nodig
#define MODE_CLOCK 1
#define MODE_TEST 10
#define MODE_SYNC 8

// Allocate the JSON document
// This one must be bigger than for the sender because it must store the strings
// https://arduinojson.org/v6/api/staticjsondocument/
StaticJsonDocument<600> docIn;
StaticJsonDocument<600> docUit;
StaticJsonDocument<100> mqtt;
DeserializationError err;
 
Preferences preferences;

// Replace with your network credentials
// https://techtutorialsx.com/2021/01/04/esp32-soft-ap-and-station-modes/amp/
const char* soft_ap_ssid     = "Wordclock-Access-Point2";
const char* soft_ap_password = "123456789";

String wifi_network_ssid = "";
String wifi_network_password =  "";

String inputSSID;
String inputWachtwoord;
IPAddress ipadres;      

unsigned long _next_1000_ms;
unsigned long _millis;

long  gmtOffset_sec = 3600;
String ntpServer = "europe.pool.ntp.org";

uint8_t minBrightness = 12;
uint8_t maxBrightness = 255;
uint8_t stepBrightness = 30; //in seconden
uint8_t startBrightness = 60; //gerekend in minuten na zonsondergang

uint8_t bRood = 255; 
uint8_t bGroen = 255; 
uint8_t bBlauw = 255; 

uint8_t bSRood = 255; 
uint8_t bSGroen = 0; 
uint8_t bSBlauw = 0; 

float longitude = 5.69;
float latitude = 53.03;

// nachtstand
uint8_t uuruit = 23;
uint8_t uuraan = 7;
uint8_t nachtsterkte = 12;

// wordclock
String wordclock = "secaan";
// effecten
String effect = "geeneffect";

uint8_t maan = true; 
uint8_t desOchtends = false; 
uint8_t hetIs = true;
 
uint8_t autoZomertijd = true; 

//String startDimmen;
//String eindeDimmen;
//String startOpdraaien;
//String eindeOpdraaien;

int jaar;
int maand;
int datum;
int uur;
int minuut;
int seconde;

AsyncWebServer server(80);

// Create a WebSocket object
AsyncWebSocket ws("/ws");

uint8_t mode = MODE_CLOCK;

float temperatuur;
float druk;
String zonop;
String zononder;
uint8_t stap;
uint8_t sterkte;
String maanfase; 

void eeprom_save() {

  // https://randomnerdtutorials.com/esp32-save-data-permanently-preferences/

  preferences.begin("settings", false);
  preferences.putUChar("mode", mode); 
  preferences.putUChar("startBr", startBrightness);
  preferences.putUChar("stepBr", stepBrightness);
  preferences.putUChar("minBr", minBrightness);
  preferences.putUChar("maxBr", maxBrightness);
  preferences.putUChar("bRood", bRood);
  preferences.putUChar("bGroen", bGroen);
  preferences.putUChar("bBlauw", bBlauw);
  preferences.putUChar("bSRood", bSRood);
  preferences.putUChar("bSGroen", bSGroen);
  preferences.putUChar("bSBlauw", bSBlauw);
  preferences.putFloat("lengte", longitude);
  preferences.putFloat("breedte", latitude);

  preferences.putUChar("uuruit", uuruit);
  preferences.putUChar("uuraan", uuraan);
  preferences.putUChar("nachtsterkte", nachtsterkte);
  
  preferences.putString("wordclock", wordclock);
  preferences.putString("effect", effect);
  
  preferences.putUChar("maan", maan);
  preferences.putUChar("desOchtends", desOchtends);
  preferences.putUChar("hetIs", hetIs);

  preferences.putString("ntpServer", ntpServer);
  preferences.putInt("gmtOffset_sec", gmtOffset_sec);
  preferences.putUChar("autoZomertijd", autoZomertijd);

  preferences.end();
    
  preferences.begin("credentials", false);
  preferences.putString("ssid", wifi_network_ssid); 
  preferences.putString("password", wifi_network_password);
  preferences.end();

}

void eeprom_retrieve() {

  preferences.begin("settings", false);
  mode = preferences.getUChar("mode", MODE_CLOCK); 
  startBrightness = preferences.getUChar("startBr", 0);
  stepBrightness = preferences.getUChar("stepBr", 15);
  minBrightness = preferences.getUChar("minBr", 20);
  maxBrightness = preferences.getUChar("maxBr", 255);
  bRood = preferences.getUChar("bRood", 255);
  bGroen = preferences.getUChar("bGroen", 255);
  bBlauw = preferences.getUChar("bBlauw", 255);
  bSRood = preferences.getUChar("bSRood", 255);
  bSGroen = preferences.getUChar("bSGroen", 255);
  bSBlauw = preferences.getUChar("bSBlauw", 255);
  longitude = preferences.getFloat("lengte", 5.69);
  latitude = preferences.getFloat("breedte", 53.03);
  
  uuruit = preferences.getUChar("uuruit", 23);
  uuraan = preferences.getUChar("uuraan", 7);
  nachtsterkte = preferences.getUChar("nachtsterkte", 12);
  
  wordclock = preferences.getString("wordclock", "secaan");
  effect = preferences.getString("effect", "geeneffect");
  
  maan = preferences.getUChar("maan", true);
  desOchtends = preferences.getUChar("desOchtends", false);
  hetIs = preferences.getUChar("hetIs", true);

  ntpServer = preferences.getString("ntpServer", "europe.pool.ntp.org");
  gmtOffset_sec = preferences.getInt("gmtOffset_sec", 3600);
  autoZomertijd = preferences.getUChar("autoZomertijd", true);

  preferences.end();  

  preferences.begin("credentials", false);
  wifi_network_ssid = preferences.getString("ssid", ""); 
  wifi_network_password = preferences.getString("password", "");
  preferences.end();
}

// Initialize SPIFFS
void initSPIFFS() {
  if (!SPIFFS.begin(true)) {
    Serial.println("An error has occurred while mounting SPIFFS");
  }
  Serial.println("SPIFFS mounted successfully");
}

String ipToString(IPAddress ip){
  String s="";
  for (int i=0; i<4; i++)
    s += i  ? "." + String(ip[i]) : String(ip[i]);
  return s;
}

String voorloopNul(int j){
  String s = "";
  if(j < 10) s = "0";
  s = s + String(j);
  return s;
}
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

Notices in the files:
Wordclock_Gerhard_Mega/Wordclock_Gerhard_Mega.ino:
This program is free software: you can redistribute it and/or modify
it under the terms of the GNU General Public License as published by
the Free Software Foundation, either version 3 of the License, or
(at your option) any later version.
